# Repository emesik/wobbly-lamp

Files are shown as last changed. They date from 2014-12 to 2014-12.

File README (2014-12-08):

wobbly lamp

Lamp which reacts to movement by changing colors.

It associates red, green and blue components with X, Y and Z axes respectively. The deflection from
initial position is linearly converted to light volume in each axis and returns to normal with
decay adjustable by a potentiometer unless the lamp gets bumped again.

Hardware required:
	* 12V supply,
	* MMA7361 accelerometer breakout board,
	* RGB LED strip or other similar light source with common anode,
	* 50x50mm single layer board to make the PCB,
	* electronic components as listed in the KiCad project (ATmega8, 3×N-FET, 3V3 regulator and
	  a bunch of resistors, capacitors and connectors),

This project aims to be an example of ATmega MCU's use of:
	* PWM (pulse width modulation),
	* ADC (analog to digital conversion),
	* interrupts (timer and ADC),

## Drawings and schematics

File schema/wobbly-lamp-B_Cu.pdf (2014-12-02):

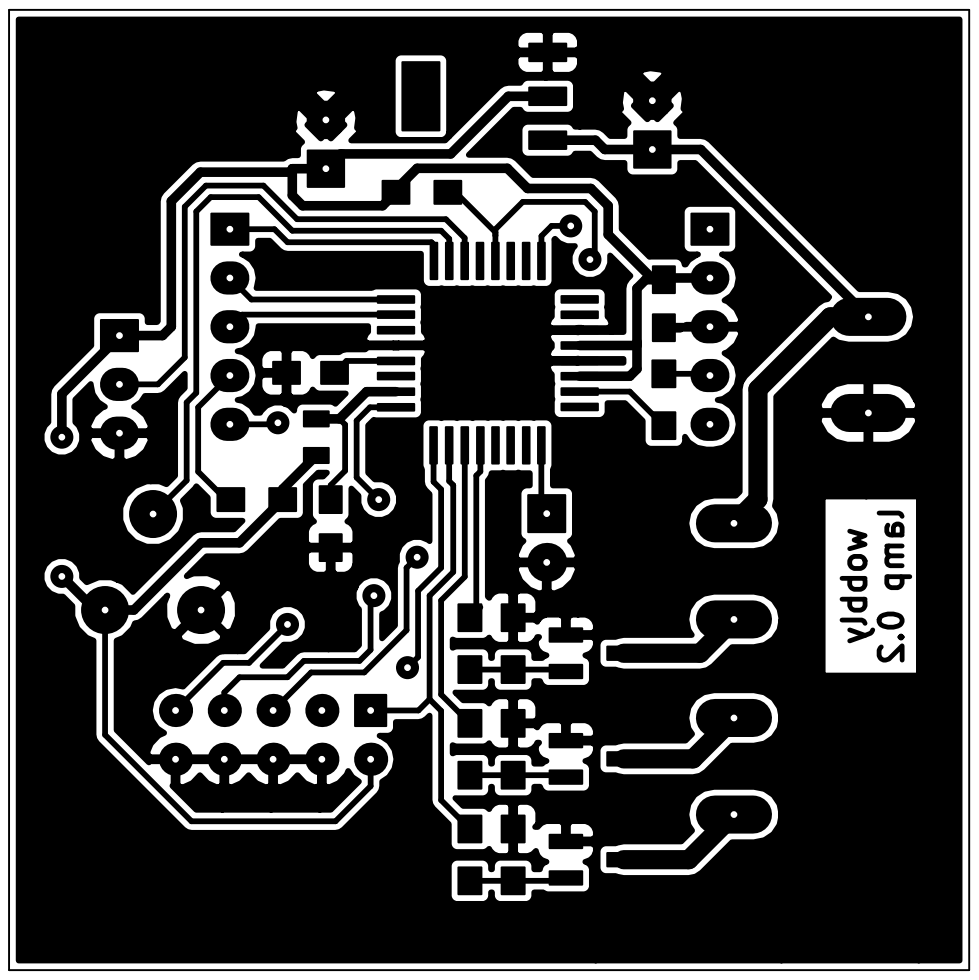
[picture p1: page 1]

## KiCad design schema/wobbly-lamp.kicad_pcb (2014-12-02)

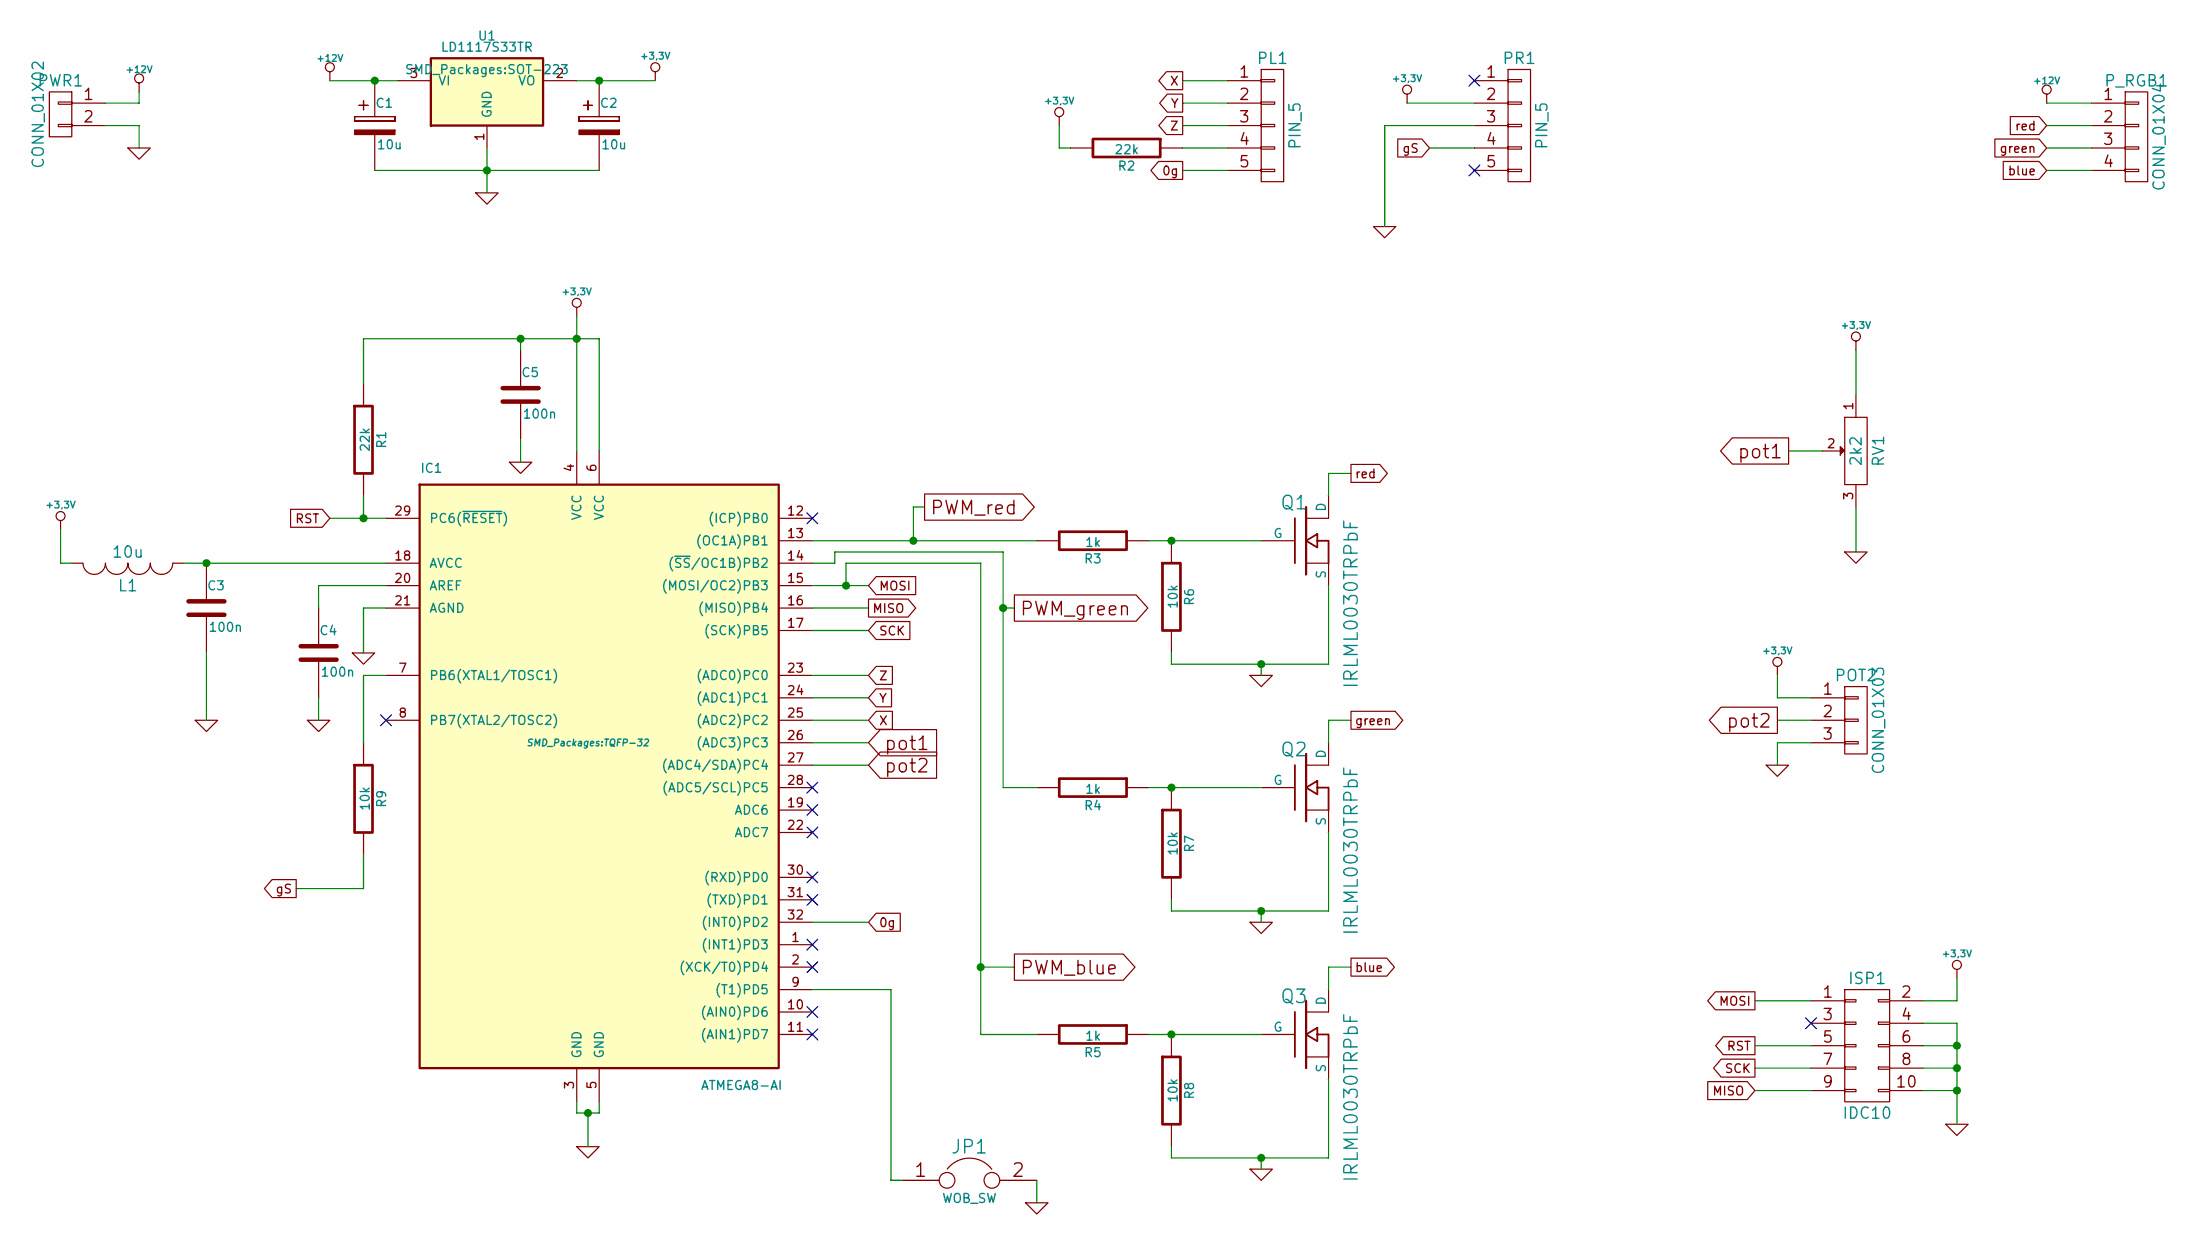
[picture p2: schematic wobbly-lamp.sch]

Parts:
C1, C2: 10u; Capacitor5x6RM2.5
C3, C4, C5: 100n; C_0805_HandSoldering
IC1: ATMEGA8-AI; TQFP-32
ISP1: IDC10; Pin_Header_Straight_2x05
JP1: WOB_SW; Pin_Header_Straight_1x02
L1: 10u; SMD-0805
PL1: PIN_5; Pin_Header_Straight_1x05
POT2: CONN_01X03; Pin_Header_Straight_1x03
PR1: PIN_5; Pin_Header_Straight_1x05
PWR1: CONN_01X02; AK300-2
P_RGB1: CONN_01X04; AK300-4
Q1, Q2, Q3: IRLML0030TRPbF; SOT23_FET_Handsoldering
R1, R2: 22k; R_0805_HandSoldering
R3, R4, R5: 1k; R_0805_HandSoldering
R6, R7, R8, R9: 10k; R_0805_HandSoldering
RV1: 2k2; Potentiometer_VishaySpectrol-Econtrim-Type36T
U1: LD1117S33TR; SOT-223

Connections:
0g: IC1.32 ((INT0)PD2), PL1.5
+3.3V: C2.1, C5.1, IC1.4 (VCC), IC1.6 (VCC), ISP1.2, L1.2, POT2.1, PR1.2, R1.1, R2.2, RV1.1, U1.2 (VO)
+12V: C1.1, PWR1.1, P_RGB1.1, U1.3 (VI)
GND: C1.2, C2.2, C3.2, C4.2, C5.2, IC1.3 (GND), IC1.5 (GND), IC1.21 (AGND), ISP1.4, ISP1.6, ISP1.8, ISP1.10, JP1.2, POT2.3, PR1.3, PWR1.2, Q1.S, Q2.S, Q3.S, R6.2, R7.2, R8.2, RV1.3, U1.1 (GND)
MISO: IC1.16 ((MISO)PB4), ISP1.9
unnamed: C3.1, IC1.18 (AVCC), L1.1
unnamed: C4.1, IC1.20 (AREF)
unnamed: IC1.7 (PB6(XTAL1/TOSC1)), R9.1
unnamed: IC1.9 ((T1)PD5), JP1.1
unnamed: PL1.4, R2.1
unnamed: Q1.G, R3.1, R6.1
unnamed: Q2.G, R4.1, R7.1
unnamed: Q3.G, R5.1, R8.1
PWM_blue: IC1.15 ((MOSI/OC2)PB3), ISP1.1, R5.2
PWM_green: IC1.14 ((~SS~/OC1B)PB2), R4.2
PWM_red: IC1.13 ((OC1A)PB1), R3.2
RST: IC1.29 (PC6(~RESET~)), ISP1.5, R1.2
SCK: IC1.17 ((SCK)PB5), ISP1.7
X: IC1.25 ((ADC2)PC2), PL1.1
Y: IC1.24 ((ADC1)PC1), PL1.2
Z: IC1.23 ((ADC0)PC0), PL1.3
blue: P_RGB1.4, Q3.D
gS: PR1.4, R9.2
green: P_RGB1.3, Q2.D
pot1: IC1.26 ((ADC3)PC3), RV1.2
pot2: IC1.27 ((ADC4/SDA)PC4), POT2.2
red: P_RGB1.2, Q1.D

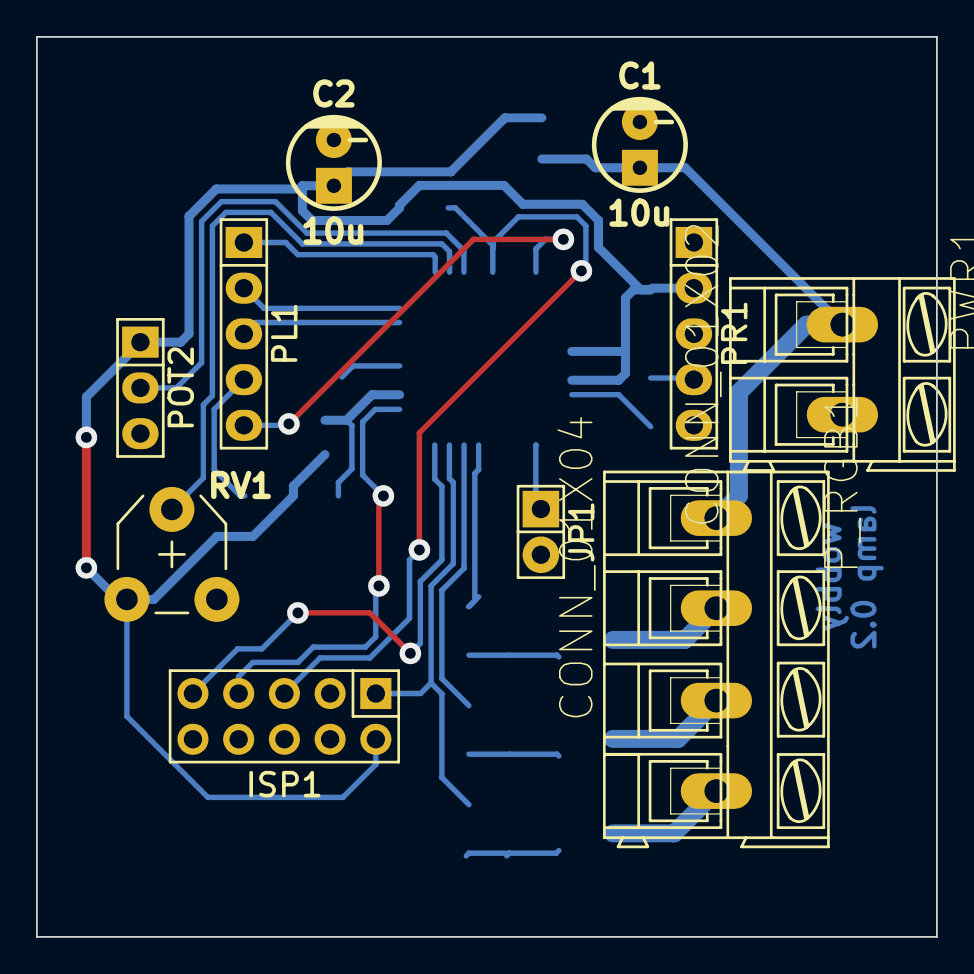
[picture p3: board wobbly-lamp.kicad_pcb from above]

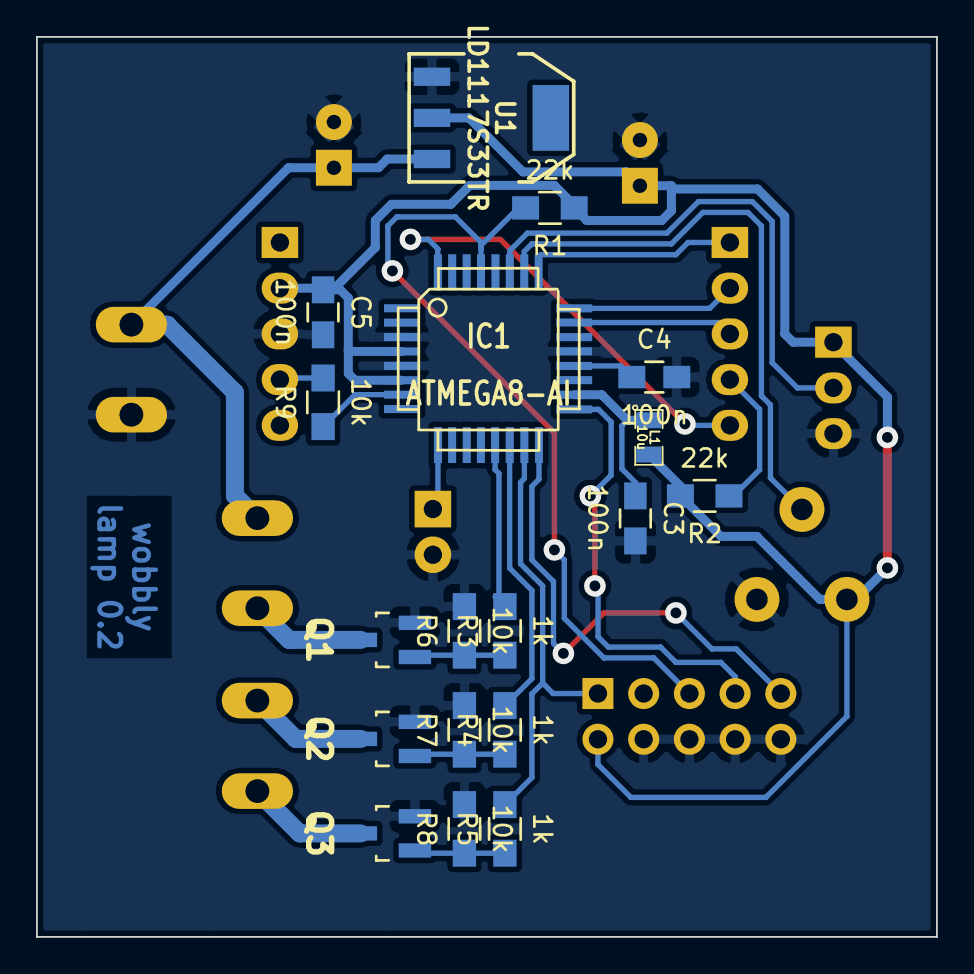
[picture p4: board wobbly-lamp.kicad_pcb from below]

Board: 2 copper layers, 50.0 x 50.0 mm, 28 parts (18 on the bottom side), 27 nets.

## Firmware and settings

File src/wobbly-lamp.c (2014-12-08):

#include <stdlib.h>
#include <string.h>
#include <avr/interrupt.h>
#include <avr/io.h>
#include <avr/pgmspace.h>
#include <util/delay.h>

// SENSORS is the number of analog inputs we read, while first DOF of them
// are accelerometer's data
#define SENSORS 4
#define DOF 3
#define DECAY_IDX 3
int16_t analog[SENSORS] = {0,0,0,0};	// X, Y, Z, decay
int16_t trail_deflection[DOF] = {0,0,0};	// trailing deflection, subject to decaying
int16_t rest[DOF] = {0,0,-0x28};	// Z adjustment for Earth's g
#define KICK_THRESHOLD 12
#define REST_THRESHOLD 4

// use Vcc as reference, left-adjust result (8b precision)
#define GENERAL_MUX (1 << REFS0) | (1 << ADLAR)
#define ALL_MUX_MASK ((1 << MUX3) | (1 << MUX2) | (1 << MUX1) | (1 << MUX0))
const uint8_t PROGMEM mux_sensors[SENSORS] = {
	(1 << MUX1),	// x @ ADC2
	(1 << MUX0),	// y @ ADC1
	0,				// z @ ADC0
	(1 << MUX1) | (1 << MUX0),	// decay @ ADC3
};
#define LOWER_SENS_THR 0xa0
#define RAISE_SENS_THR 0x20
uint8_t inlowsensmode = 0;	// 6g instead of 1.5g enabled

#define BASE_LIGHT_VOLUME	0xa0
int16_t level[DOF] = {BASE_LIGHT_VOLUME, BASE_LIGHT_VOLUME, BASE_LIGHT_VOLUME};
uint16_t decay_period = 0x10;

const uint8_t PROGMEM gamma[0x100] = {
	0,  0,  0,  0,  0,  0,  0,  0,  0,  0,  0,  0,  0,  0,  0,  0,
	0,  0,  0,  0,  0,  0,  0,  0,  0,  0,  0,  0,  1,  1,  1,  1,
	1,  1,  1,  1,  1,  1,  1,  1,  1,  2,  2,  2,  2,  2,  2,  2,
	2,  3,  3,  3,  3,  3,  3,  3,  4,  4,  4,  4,  4,  5,  5,  5,
	5,  6,  6,  6,  6,  7,  7,  7,  7,  8,  8,  8,  9,  9,  9, 10,
	10, 10, 11, 11, 11, 12, 12, 13, 13, 13, 14, 14, 15, 15, 16, 16,
	17, 17, 18, 18, 19, 19, 20, 20, 21, 21, 22, 22, 23, 24, 24, 25,
	25, 26, 27, 27, 28, 29, 29, 30, 31, 32, 32, 33, 34, 35, 35, 36,
	37, 38, 39, 39, 40, 41, 42, 43, 44, 45, 46, 47, 48, 49, 50, 50,
	51, 52, 54, 55, 56, 57, 58, 59, 60, 61, 62, 63, 64, 66, 67, 68,
	69, 70, 72, 73, 74, 75, 77, 78, 79, 81, 82, 83, 85, 86, 87, 89,
	90, 92, 93, 95, 96, 98, 99,101,102,104,105,107,109,110,112,114,
	115,117,119,120,122,124,126,127,129,131,133,135,137,138,140,142,
	144,146,148,150,152,154,156,158,160,162,164,167,169,171,173,175,
	177,180,182,184,186,189,191,193,196,198,200,203,205,208,210,213,
	215,218,220,223,225,228,231,233,236,239,241,244,247,249,252,255};

// the default white balance
const int16_t PROGMEM bias[DOF] = {10,6,-6};

#define	RED		OCR1A
#define	GREEN	OCR1B
#define	BLUE	OCR2

void init_lights() {
	DDRB |= (1 << PB1) | (1 << PB2) | (1 << PB3);
	PORTB |= (1 << PB1) | (1 << PB2) | (1 << PB3);
	// timers on /8 prescalers, phase-correct PWM
	TCCR1A = (1 << COM1A1) | (1 << COM1B1) | (1 << WGM10);
	TCCR1B = (1 << CS11);
	TCCR2 = (1 << WGM20) | (1 << COM21) | (1 << CS21);
	RED = GREEN = BLUE = 0;
}

inline void go_lowsens() {
	PORTB |= (1 << PB6);
	inlowsensmode = 1;
}

inline void go_hisens() {
	PORTB &= ~(1 << PB6);
	inlowsensmode = 0;
}

void init_sensors() {
	// X, Y, Z, decay inputs
	DDRC = 0xff & ~((1 << PC3) | (1 << PC2) | (1 << PC1) | (1 << PC0));
	DDRD &= ~(1 << PD2);									// 0g digital
	DDRB |= (1 << PB6);										// g-select digital output
	go_lowsens();
	ADMUX = GENERAL_MUX | pgm_read_byte(&mux_sensors[0]);
	// enable ADC, turn on interrupt, /128 prescaler giving 62,5kHz
	ADCSRA = (1 << ADEN) | (1 << ADIE) | (1 << ADPS2) | (1 << ADPS1) | (1 << ADPS0);
	// start first conversion
	ADCSRA |= (1 << ADSC);
}

ISR(ADC_vect) {
	static uint8_t inc_sens = 1, dec_sens = 0;
	int16_t val;
	uint8_t sensor = 0;	// currently measured axis

	// check which axis has been measured
	for (sensor = 0; sensor < DOF; sensor++) {
		if ((ADMUX & ALL_MUX_MASK) == pgm_read_byte(&mux_sensors[sensor]))
			break;
	}

	// read the analog value
	val = ADCH;
	if (sensor < DOF) {
		// X, Y, Z get normalized to 0
		val -= 0x80;
		// rescale 6g to 1.5g if we are in low sensitivity mode
		if (inlowsensmode) val = val * 4;
	}

	// store the value
	analog[sensor] = val;
	// next input
	sensor = (sensor + 1) % SENSORS;

	// If ANY axis had high value, we should probably go to lower sensitivity mode.
	// If ALL axes have low values, we might enable hi sensitivity mode.
	if (sensor < DOF) {
		if (abs(val) > LOWER_SENS_THR) dec_sens = 1;
		if (abs(val) >= RAISE_SENS_THR) inc_sens = 0;
	}

	if (sensor == 0) {	// once all sensors have been probed
		// set sensitivity
		if (!inlowsensmode && dec_sens) {
			// TODO: never happens. why?
			go_lowsens();
		}
		if (inlowsensmode && inc_sens && !dec_sens) {
			go_hisens();
		}

		// reset all local flags
		inc_sens = 1;
		dec_sens = 0;

		for (uint8_t i=0; i < DOF; i++) {
			int16_t defl;
			// if current deflection from rest is bigger than the decaying one,
			// use it as the new value
			defl = analog[i] - rest[i];
			if (abs(defl) < REST_THRESHOLD) defl = 0;
			if (abs(defl) > abs(trail_deflection[i]) + KICK_THRESHOLD)
				trail_deflection[i] = defl;
		}
	}

	// reset all MUX bits then set to next axis
	ADMUX = GENERAL_MUX | pgm_read_byte(&mux_sensors[sensor]);

	// start conversion again
	ADCSRA |= (1 << ADSC);
}

void init_decay() {
	TCCR0 |= (1 << CS01) | (1 << CS00);	// prescaler /64
	TIMSK |= (1 << TOIE0);
}

uint8_t get_pwm_value(uint8_t color, int16_t lev) {
	lev += pgm_read_word(&bias[color]);
	// make sure that level is within bounds
	if (lev < 0) lev = 0;
	if (lev > 0xff) lev = 0xff;
	return pgm_read_byte(&gamma[(uint8_t)lev]);
}

ISR(TIMER0_OVF_vect) {
	static uint16_t decay_overflows = 0;
	uint8_t ax;
	int16_t d;

	// disable interrupts
	cli();

	// do the decay
	if (++decay_overflows >= analog[DECAY_IDX]) {
		for (ax=0; ax<DOF; ax++) {
			if (trail_deflection[ax] > 0) trail_deflection[ax]--;
			else if (trail_deflection[ax] < 0) trail_deflection[ax]++;
		}
		decay_overflows = 0;
	}

	// deflections to levels
	d = 0;
	for (ax=0; ax<DOF; ax++) {
		level[ax] = trail_deflection[ax] + BASE_LIGHT_VOLUME;
		d += trail_deflection[ax];
	}
	d = d / DOF;
	// equalize total light amount
	// what is added to one channel gets subtracted from others
	for (ax=0; ax<DOF; ax++) {
		level[ax] -= d;
	}
	RED   = get_pwm_value(0, level[0]);
	GREEN = get_pwm_value(1, level[1]);
	BLUE  = get_pwm_value(2, level[2]);

	sei();
}

int main()
{
	init_lights();
	sei();
	init_sensors();
	// make sure we have some stable measurement
	_delay_ms(100);
	// store current position as rest
	// TODO: update rest on inactivity
	for (int ax=0; ax<DOF; ax++) {
		rest[ax] = analog[ax];
	}
	// now we can initialize the decay timer
	init_decay();
	while (1) {};
}

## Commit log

2014-11-28 Add schema
    [wobbly-lamp.kicad_pcb, wobbly-lamp.sch]
2014-11-28 Redraw PCB
    [wobbly-lamp.kicad_pcb]
2014-11-30 Add missing path
    [wobbly-lamp.kicad_pcb]
2014-12-02 Remove all stuff related to LCD, the working PCB doesn't support it
    [wobbly-lamp.c]
2014-12-02 Add first working PCB, tiny version
    [wobbly-lamp.kicad_pcb, wobbly-lamp.sch]
2014-12-08 Determine current axis by re-reading of ADMUX instead of global counter
2014-12-08 Read decay period from potentiometer, use phase correct PWM
    [wobbly-lamp.c]
2014-12-08 Fix bug with potentiometer input treated as signed value
    [wobbly-lamp.c]
2014-12-08 Fix reverse equalization of light volume
    [wobbly-lamp.c]
